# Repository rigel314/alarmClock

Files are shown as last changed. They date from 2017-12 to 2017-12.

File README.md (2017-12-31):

alarmClock
========
# About
My fiancé wanted an alarm clock that simulated a sunrise before ringing.  Since all the ones you can buy are expensive, dumb, or both, I decided to make one.

# Dependencies
 * [My fork of firelizzard's Nokia LCD library](https://github.com/rigel314/Arduino-LCD-Screen), which is a submodule
  * This should be installed as a normal Arduino library. For me, this was:
    * `git submodule update --init`
    * `cp -a Arduino-LCD-Screen ../../libraries/`
 * [TimerOne](https://github.com/PaulStoffregen/TimerOne) as installed by the teensy installer
 * [TimeLib](https://github.com/PaulStoffregen/Time) as installed by the teensy installer
 * [DS1307RTC](https://github.com/PaulStoffregen/DS1307RTC) as installed through the Arduino IDE "Manage Libraries" interface

# Hardware
 * 3-color LED strip
 * Resistors and transistors
 * DS1307 Real Time Clock
 * MCP4725 I2C DAC for audio
 * Speaker
 * Nokia 5110 84x48 pixel LCD screen
 * Arduino Duemilanove/Uno with atmega328P
 * 12V power supply

See the [/eagle](https://github.com/rigel314/alarmClock/tree/master/eagle) folder in this repo for the board layout.
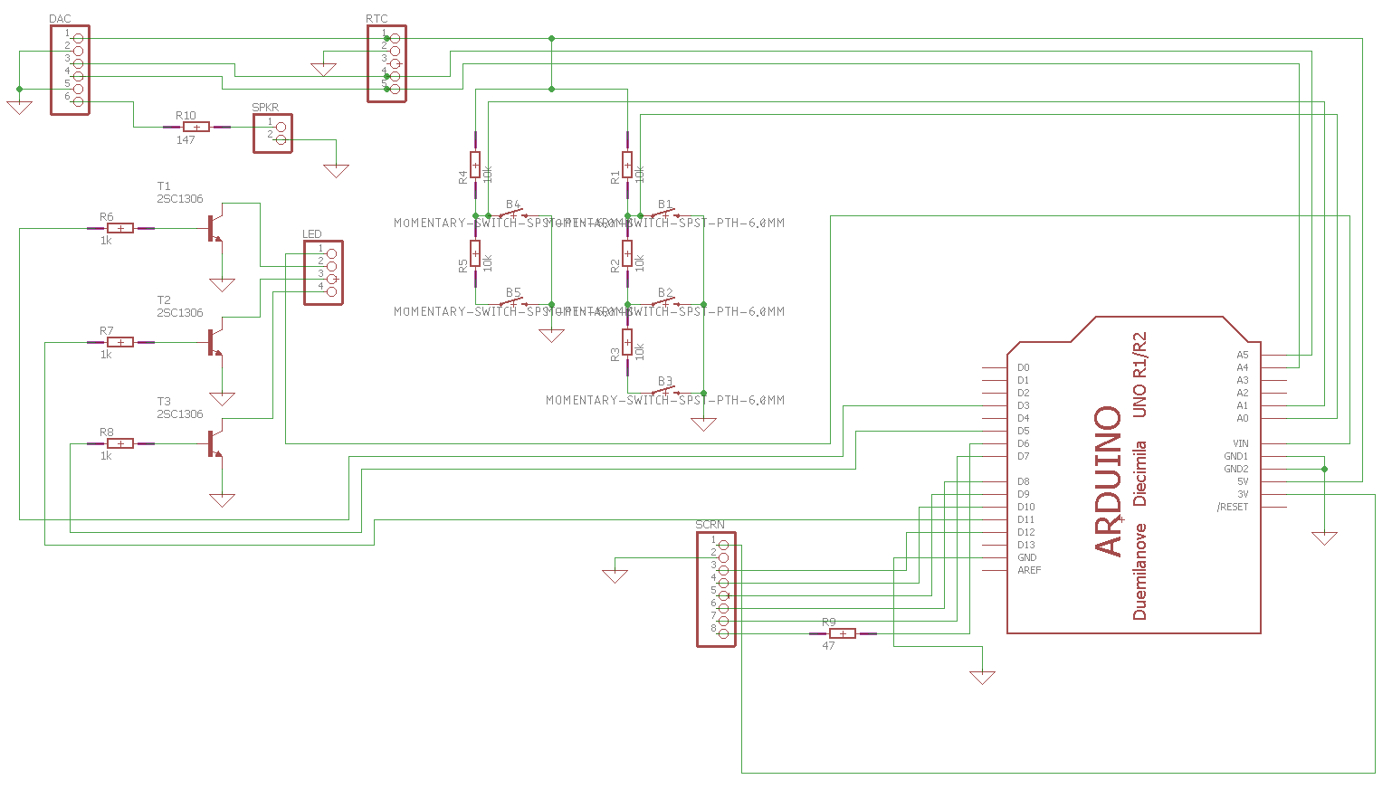
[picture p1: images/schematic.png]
Schematic


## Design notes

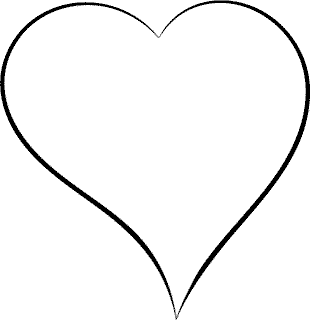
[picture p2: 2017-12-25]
images/heart-320.bmp

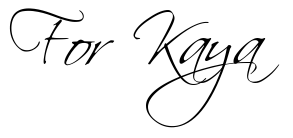
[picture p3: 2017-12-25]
images/forkaya.PNG

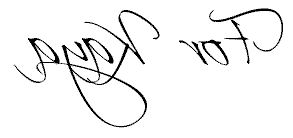
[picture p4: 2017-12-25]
images/forkaya.bmp

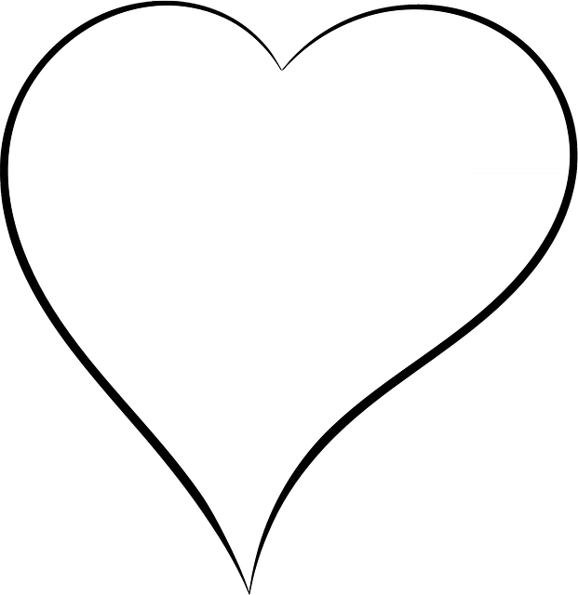
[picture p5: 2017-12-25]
images/heart-264496_640.png

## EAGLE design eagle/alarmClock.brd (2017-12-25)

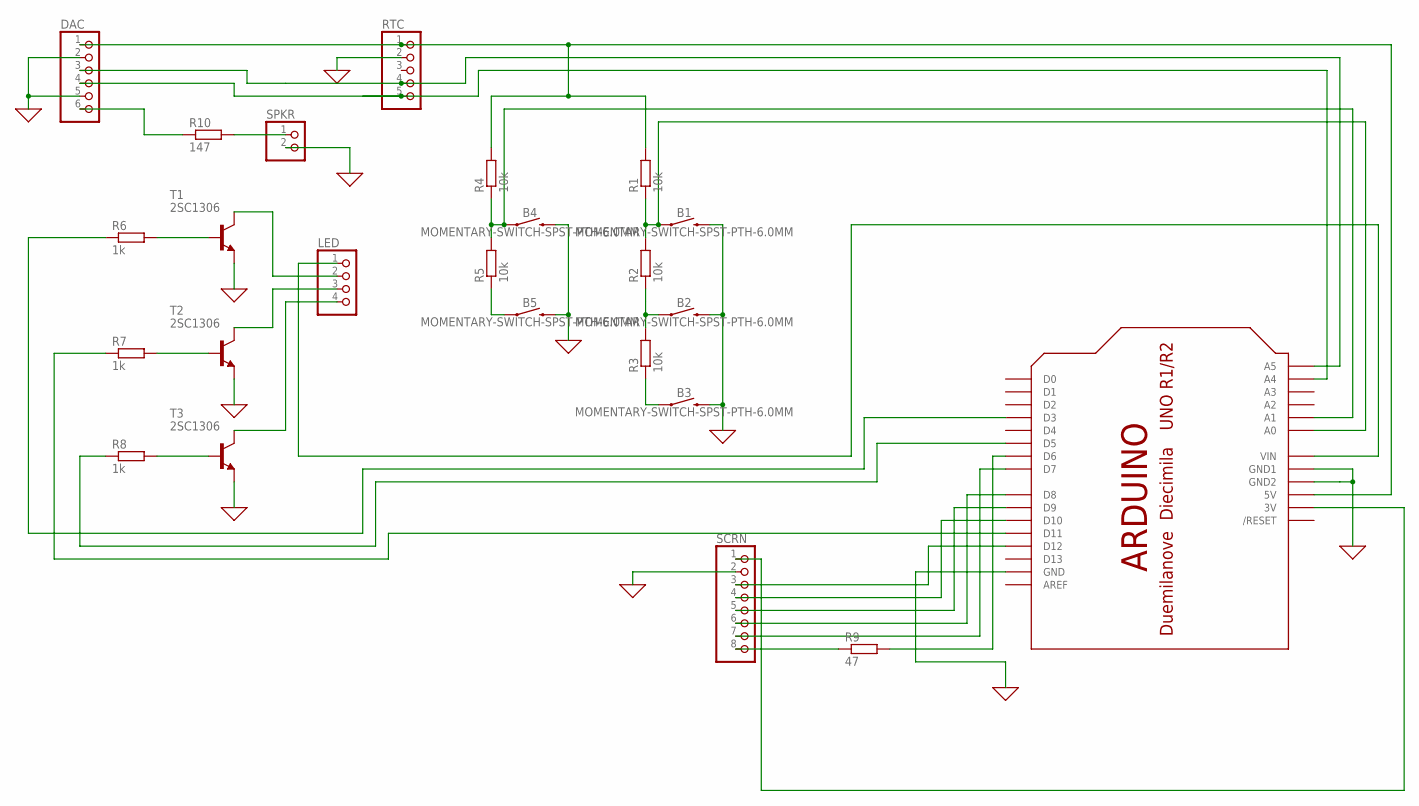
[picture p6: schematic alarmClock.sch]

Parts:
B1, B2, B3, B4, B5: MOMENTARY-SWITCH-SPST-PTH-6.0MM; TACTILE_SWITCH_PTH_6.0MM
DAC: PINHD-1X6; 1X06
LED: PINHD-1X4; 1X04
R1, R2, R3, R4, R5: 10k; 0204/7
R6, R7, R8: 1k; 0204/7
R9: 47; 0204/7
R10: 147; 0204/7
RTC: PINHD-1X5; 1X05
SCRN: PINHD-1X8; 1X08
SPKR: PINHD-1X2; 1X02
T1, T2, T3: 2SC1306; TO220BV
U$1: ARDUINOUNO; ARDUINO

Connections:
0: B1.3 (2), B2.3 (2), B3.3 (2), B4.3 (2), B5.3 (2), DAC.2, DAC.5, RTC.2, SCRN.2, SPKR.2, T1.3 (E), T2.3 (E), T3.3 (E), U$1.GND, U$1.GND1, U$1.GND2
unnamed: B1.1, R1.1, R2.2, U$1.A0
unnamed: B3.1, R3.1
unnamed: B2.1, R2.1, R3.2
unnamed: B5.1, R5.1
unnamed: B4.1, R4.1, R5.2, U$1.A1
unnamed: R6.2, T1.1 (B)
unnamed: R8.2, T3.1 (B)
unnamed: R7.2, T2.1 (B)
unnamed: DAC.4, RTC.5, U$1.A4
unnamed: DAC.3, RTC.4, U$1.A5
unnamed: DAC.1, R1.2, R4.2, RTC.1, U$1.5V
unnamed: DAC.6, R10.1
unnamed: LED.1, U$1.VIN
unnamed: LED.2, T1.2 (C)
unnamed: LED.4, T3.2 (C)
unnamed: LED.3, T2.2 (C)
unnamed: R6.1, U$1.D3
unnamed: R8.1, U$1.D5
unnamed: SCRN.7, U$1.D7
unnamed: R9.2, U$1.D6
unnamed: SCRN.6, U$1.D8
unnamed: R7.1, U$1.D11
unnamed: SCRN.5, U$1.D9
unnamed: SCRN.4, U$1.D10
unnamed: SCRN.3, U$1.D12
unnamed: SCRN.1, U$1.3V
unnamed: R9.1, SCRN.8
unnamed: R10.2, SPKR.1

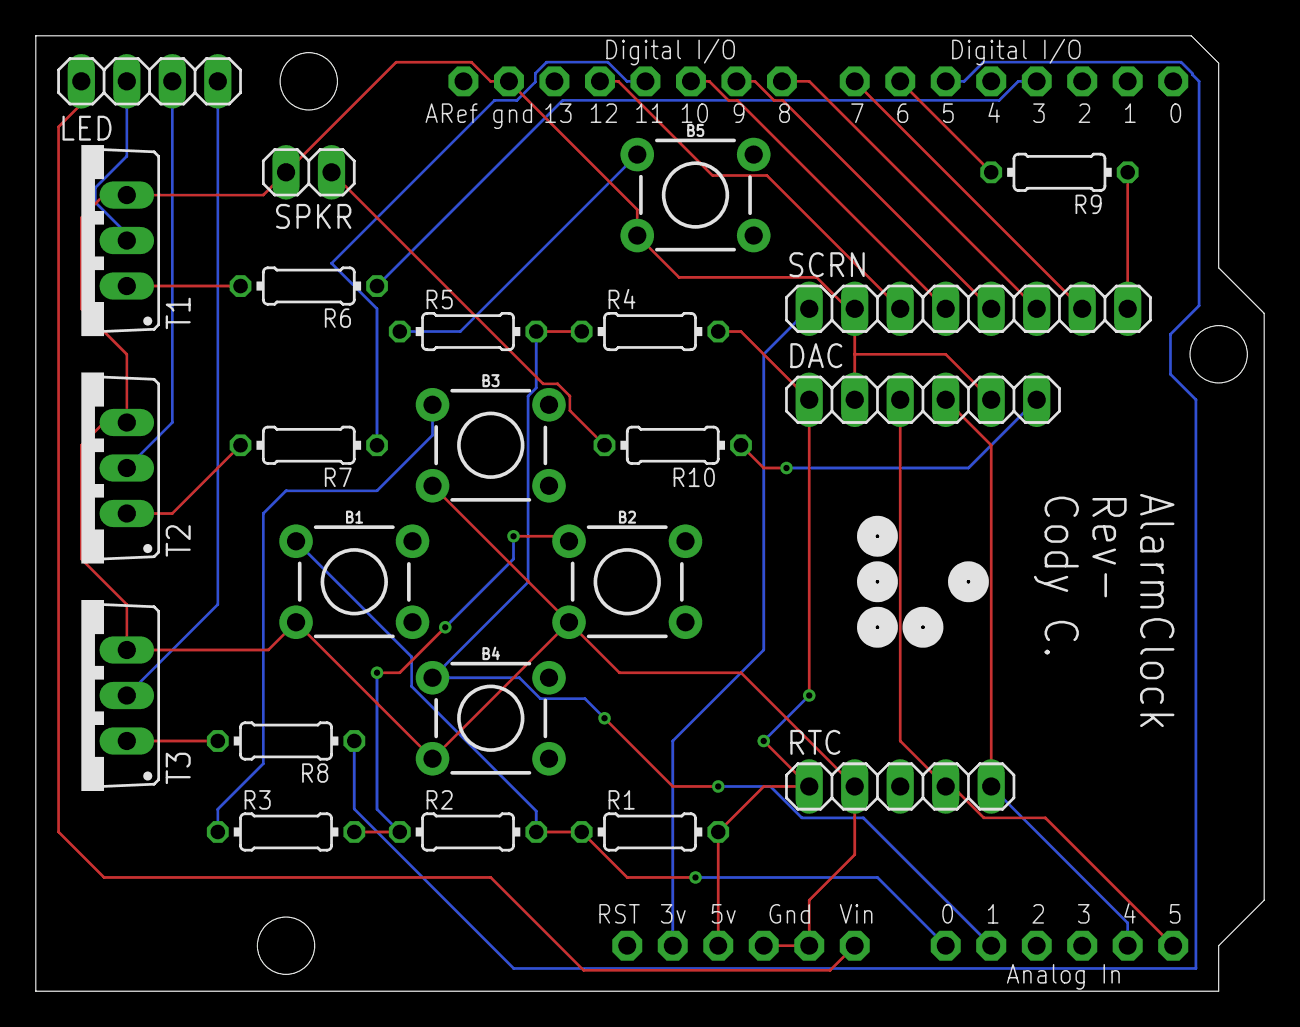
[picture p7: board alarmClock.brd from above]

Board: 2 copper layers, 68.6 x 53.3 mm, 24 parts (0 on the bottom side), 29 nets.

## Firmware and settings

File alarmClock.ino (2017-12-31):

// TODO: add function that prints a help icon on the screen that takes an array of enums, which are indexes into a string table.
// TODO: add 2min timeout for modes that goes back to normal mode, so the alarm still goes off.
// TODO: reverify 8kHz sound, since I removed a mask

#include <TimerOne.h>
#include <TimeLib.h>
#include <DS1307RTC.h>
#include <Wire.h>
#include <avr/pgmspace.h>
// #include <EEPROM.h>

#include "common.h"
#include "modes.h"

volatile unsigned char gotTimer1 = 0;

LCD lcd(SCRN_SCLK_PIN, SCRN_MOSI_PIN, SCRN_DC_PIN, SCRN_RST_PIN, SCRN_SCE_PIN);

const char sound[] PROGMEM =
#include "bird.h" // This has the data and a semicolon

const char lookup[] = "0123456789ABCDEF";
const char* emptyLine = "              ";

struct alarm alarms[nALARMS] = {{0,0,0}};

// Called via timer interrupt
void timer1inter()
{
	gotTimer1 = 1;
	// logobj("inter");
}

void setup()
{
	Serial.begin(115200); // For debug (owns pins 0 and 1)
	
	// TWBR = ((F_CPU / 400000L) - 16) / 2; // Set I2C frequency to 400kHz
	Wire.setClock(400000L);
	
	Timer1.initialize(1000000);
	Timer1.attachInterrupt(timer1inter);
	
	lcd.initialize();
	lcd.sendCommands("\x21\xAC\x20");
	
	// set time sync to read from the RTC every 5min. (which is actually sync()'d in now() if it detects elapsed time >= 300s)
	setSyncProvider(RTC.get);
	// setSyncInterval(10);
	
	// Initial screen
	tmElements_t tm;
	breakTime(now(), tm);
	char timestr[] = "now - 15:37   ";
	timestr[6] = lookup[tm.Hour/10];
	timestr[7] = lookup[tm.Hour%10];
	timestr[9] = lookup[tm.Minute/10];
	timestr[10] = lookup[tm.Minute%10];
	lcd.sendString(0, 0, timestr);
	lcd.sendString(5, 0, "mode: NORMAL");
	
	// Set pin directions
	pinMode(BUT_PIN1, INPUT);
	pinMode(BUT_PIN2, INPUT);
	
	pinMode(RED_PIN, OUTPUT);
	pinMode(GRN_PIN, OUTPUT);
	pinMode(BLU_PIN, OUTPUT);
	
	// get saved settings
	// TODO: read alarm time and other settings(backlight intensity?) from EEPROM/RTCram
}

void loop()
{
	static enum but prevBut = but_NONE;
	static int prev1Val = 0;
	static int prev2Val = 0;
	static char backlight = 0;
	static enum mode mode = mode_NORMAL;
	static char longPress = 0;
	static int longCount = 0;
	
	enum but but, realbut;
	
	// Handle interrupt
	if(gotTimer1)
	{
		gotTimer1 = 0;
		tmElements_t tm;
		
		breakTime(now(), tm);
		
		char timestr[] = "now - 15:37   ";
		
		timestr[6] = lookup[tm.Hour/10];
		timestr[7] = lookup[tm.Hour%10];
		timestr[9] = lookup[tm.Minute/10];
		timestr[10] = lookup[tm.Minute%10];
		
		lcd.sendString(0, 0, timestr);
	}
	
	// Figure out which button is pressed
	int but1Val = analogRead(BUT_PIN1);
	int but2Val = analogRead(BUT_PIN2);
	
	if(histequal(but1Val, prev1Val, 10) && histequal(but2Val, prev2Val, 10))
	{
		if(histequal(but1Val, 1024, 20) && histequal(but2Val, 1024, 20))
			but = but_NONE;
		else if(histequal(but1Val, 0, 70))
			but = but_LEFT;
		else if(histequal(but1Val, 512, 70))
			but = but_RIGHT;
		else if(histequal(but1Val, 682, 70))
			but = but_UP;
		else if(histequal(but2Val, 0, 70))
			but = but_DOWN;
		else if(histequal(but2Val, 512, 70))
			but = but_SELECT;
		else
			but = prevBut;
	}
	else
	{
		but = prevBut;
	}
	
	// Don't send a button event unless a button has been released
	realbut = but_NONE;
	if(but == but_NONE && prevBut != but_NONE) // button released
	{
		if(longPress) // Also don't send one if longpress was sent
			longPress = 0;
		else
			realbut = prevBut;
		longCount = 0;
	}
	
	if(longCount == 5000 && !longPress)
	{
		longPress = 1;
		realbut = (enum but)(but + 5);
	}
	if(but != but_NONE)
	{
		if(longPress && longCount % 200 == 1)
		{
			realbut = (enum but)(but + 10); // Unless a repeat should be sent
		}
		longCount++;
	}
	
	// handle buttons globally
	if(realbut == but_SELECT_LONG)
	{
		// logwobj("B5", but2Val);
		realbut = but_NONE;
		backlight = !backlight;
		analogWrite(SCRN_LED_PIN, (backlight) ? 10 : 0);
	}
	
	enum mode modebak = mode;
	
	mode = modeMux(mode, &realbut);
	
	// default actions for buttons
	if(realbut == but_LEFT)
		mode = (enum mode)(mode - 1);
	if(realbut == but_RIGHT)
	{
		mode = (enum mode)(mode + 1);
		// logwobj("default mode++ handler", modebak);
	}
	
	if(mode == mode_NMODES)
	{
		mode = mode_NORMAL;
	}
	if(mode == mode_INVALID)
	{
		// logwobj("default invalid mode handler", modebak);
		mode = mode_DEMO;
	}
	
	if(mode != modebak)
	{
		switch(mode)
		{
			default:
				logwobj("weird mode", mode);
				mode = mode_NORMAL;
				// intentional fallthrough
			case mode_NORMAL:
				lcd.sendString(5, 0, "mode: NORMAL  ");
				break;
			case mode_SETTIME:
				lcd.sendString(5, 0, "mode: SETTIME ");
				break;
			case mode_SETALARM:
				lcd.sendString(5, 0, "mode: SETALARM");
				break;
			case mode_DEMO:
				lcd.sendString(5, 0, "mode: DEMO    ");
				break;
		}
	}
	
	prevBut = but;
	prev1Val = but1Val;
	prev2Val = but2Val;
}

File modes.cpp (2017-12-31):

#include <Arduino.h>
#include <Wire.h>
#include <TimeLib.h>
#include <DS1307RTC.h>

#include "modes.h"

static const char* fields[] = {"year", "month", "day", "hour", "minute", "second"};
static const uint8_t min[] = {0, 1, 1, 0, 0, 0};
static uint8_t max[] = {255, 12, 31, 23, 59, 59};
const char* days = "SMTWHFS";

#define LEAP_YEAR(Y) ( ((1970+Y)>0) && !((1970+Y)%4) && ( ((1970+Y)%100) || !((1970+Y)%400) ) )

static const uint8_t monthDays[]={31,28,31,30,31,30,31,31,30,31,30,31}; // API starts months from 1, this array starts from 0

enum mode normmode(enum mode mode, enum but* butp)
{
	enum but but = *butp;
	(void) but;
	return mode;
}

enum mode stimemode(enum mode mode, enum but* butp)
{
	static char entry = 0;
	static tmElements_t tm;
	char len;
	
	enum but but = *butp;
	
	if(!entry && but == but_SELECT)
	{
		*butp = but_NONE;
		entry = 1;
		breakTime(now(), tm);
		char str[15];
		len = snprintf(str, 15, "%s: %04d", fields[0], (int)tm.Year + 1970);
		for(int i = len; i < 14; i++)
			str[i] = ' ';
		str[14] = '\0';
		lcd.sendString(4, 0, str);
		
		return mode;
	}
	
	if(entry)
	{
		char str[15];
		
		uint8_t* fld = &((uint8_t*)&tm)[7-entry-(entry > 3)]; // index into the correct field in the tmElements_t struct
		// if(but != but_NONE)
		// 	logwobj("offset", (int)(fld - (uint8_t*)&tm));
		int val = (int)*fld;
		int off = 0;
		const char* fmt = "%s: %02d";
		if(entry == 1)
		{
			off = 1970; // Adjust year
			fmt = "%s: %04d";
		}
		
		max[2] = monthDays[tm.Month - 1];
		if(tm.Month == 2 && LEAP_YEAR(tm.Year))
		{
			max[2] = 29;
		}
		if(tm.Day > max[2])
		{
			tm.Day = max[2];
		}
		
		switch(but)
		{
			case but_LEFT:
				entry--;
				break;
				
			case but_SELECT:
				entry = 6;
				// Intentional fallthrough
			case but_RIGHT:
				entry++;
				if(entry == 7)
				{
					time_t tme = makeTime(tm);
					RTC.set(tme);
					setTime(tme);
					entry = 0;
				}
				break;
			
			case but_UP:
			case but_UP_RPT:
				if(val < max[entry - 1])
					(*fld)++;
				val = *fld;
				val += off; // Adjust year
				len = snprintf(str, 15, fmt, fields[entry - 1], val);
				for(int i = len; i < 14; i++)
					str[i] = ' ';
				str[14] = '\0';
				lcd.sendString(4, 0, str);
				break;
			
			case but_DOWN:
			case but_DOWN_RPT:
				if(val > min[entry - 1])
					(*fld)--;
				val = *fld;
				val += off; // Adjust year
				len = snprintf(str, 15, fmt, fields[entry - 1], val);
				for(int i = len; i < 14; i++)
					str[i] = ' ';
				str[14] = '\0';
				lcd.sendString(4, 0, str);
				break;
				
			default:
				break;
		}
		if((but == but_LEFT || but == but_RIGHT) && entry)
		{
			off = 0;
			fmt = "%s: %02d";
			if(entry == 1)
			{
				off = 1970; // Adjust year
				fmt = "%s: %04d";
			}
			
			fld = &((uint8_t*)&tm)[7-entry-(entry > 3)];
			val = *fld;
			val += off;
			len = snprintf(str, 15, fmt, fields[entry - 1], val);
			for(int i = len; i < 14; i++)
				str[i] = ' ';
			str[14] = '\0';
			lcd.sendString(4, 0, str);
		}
		if(entry == 0)
		{
			lcd.sendString(4, 0, (char*)emptyLine);
		}
		
		*butp = but_NONE;
	}
	
	return mode;
}

enum mode salrmmode(enum mode mode, enum but* butp)
{
	static char entry = 0;
	static char newentry = 0;
	static int alarmChoice;
	static char val = 0;
	// static char newval = 0;
	static struct alarm alrm = {0,0,0};
	
	char len;
	enum but but = *butp;
	
	// begin entry
	if(!entry && but == but_SELECT)
	{
		char str[19];
		*butp = but_NONE;
		entry = 1;
		alarmChoice = 0;
		alrm = alarms[alarmChoice];
		if(nALARMS == 1) // Maybe make this an #if
		{
			entry++;
			val = alrm.hour;
			len = snprintf(str, 19, "set: %s%02d%s:%02d", LCD::reverseVideoOn, (int)alrm.hour, LCD::reverseVideoOff, (int)alrm.min);
		}
		else
		{
			val = alarmChoice;
			len = snprintf(str, 19, "alarm: %d", (int)alarmChoice+1);
		}
		for(int i = len; i < 18; i++)
			str[i] = ' ';
		str[18] = '\0';
		lcd.sendString(4, 0, str);
		
		return mode;
	}
	
	// actually do entry
	if(entry)
	{
		// logwobj("but IN:", *butp);
		char str[19];
		char str3[15];
		newentry = entry;
		// newval = val;
		
		// handle buttons
		switch(but)
		{
			case but_LEFT:
				newentry--;
				if(nALARMS == 1 && newentry == 1)
					newentry--;
				break;
				
			case but_SELECT:
				newentry = 11;
				// Intentional fallthrough
			case but_RIGHT:
				newentry++;
				if(newentry == 12)
				{
					newentry = 0;
				}
				break;
			
			case but_UP:
			case but_UP_RPT:
				val++;
				break;
			
			case but_DOWN:
			case but_DOWN_RPT:
				val--;
				break;
				
			default:
				break;
		}
		
		char entrychanged = (entry != newentry);
		char shft = (6-(entry-5)); // bit shift for weekday selection
		
		// update storage variable on entry change for the entry you just left
		if(entrychanged)
		{
			switch(entry)
			{
				case 1:
					alarmChoice = val;
					break;
				case 2:
					alrm.hour = val;
					break;
				case 3:
					alrm.min = val;
					break;
				case 4:
					alrm.enDayEn = (alrm.enDayEn & 0x7F) | val<<7;
					break;
				case 5:
				case 6:
				case 7:
				case 8:
				case 9:
				case 10:
				case 11:
					alrm.enDayEn = (alrm.enDayEn & ~(1 << shft)) | (val << shft);
					// logwobj("enDayEn", (int)alrm.enDayEn, HEX);
					break;
				default:
					break;
			}
		}
		
		entry = newentry;
		// val = newval;
		
		strcpy(str3, emptyLine);
		
		char len;
		shft = (6-(entry-5)); // calculate this again on the new entry
		
		// create correct line 4 for newentry and newval
		// update temp var from storage var on entry change for the entry you just changed to
		switch(entry)
		{
			case 1:
				if(entrychanged)
					val = alarmChoice;
				if(val < 1)
					val = nALARMS;
				if(val > nALARMS)
					val = 1;
				len = snprintf(str, 19, "alarm: %s%d%s", LCD::reverseVideoOn, val, LCD::reverseVideoOff);
				break;
			case 2:
				if(entrychanged)
					val = alrm.hour;
				if(val < 0)
					val = 23;
				if(val > 23)
					val = 0;
				len = snprintf(str, 19, "set: %s%02d%s:%02d", LCD::reverseVideoOn, (int)val, LCD::reverseVideoOff, (int)alrm.min);
				break;
			case 3:
				if(entrychanged)
					val = alrm.min;
				if(val < 0)
					val = 59;
				if(val > 59)
					val = 0;
				len = snprintf(str, 19, "set: %02d:%s%02d%s", (int)alrm.hour, LCD::reverseVideoOn, (int)val, LCD::reverseVideoOff);
				break;
			case 4:
				if(entrychanged)
					val = !!(alrm.enDayEn & 0x80);
				if(val < 0)
					val = 1;
				if(val > 1)
					val = 0;
				len = snprintf(str, 19, "enable: %s%s%s", LCD::reverseVideoOn, (val) ? "yes" : "no", LCD::reverseVideoOff);
				break;
			case 5:
			case 6:
			case 7:
			case 8:
			case 9:
			case 10:
			case 11:
				if(entrychanged)
					val = !!(alrm.enDayEn & (1 << shft));
				if(val < 0)
					val = 1;
				if(val > 1)
					val = 0;
				len = 16;
				strcpy(str, "on: ");
				strcpy(str3, "off:");
				for(int i = 0; i < 7; i++)
				{
					uint8_t curval = (alrm.enDayEn & ~(1 << shft)) | (val << shft);
					if(i == entry-5)
						memcpy(&str[4+i], LCD::reverseVideoOn, 2);
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

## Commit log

2017-12-23 Add LED strip and Screen commanding
2017-12-23 sane buttons
2017-12-24 Add Eagle project
    [alarmClock.brd, alarmClock.sch]
2017-12-25 Add bird noise PoC
    [alarmClock.ino]
2017-12-25 Update Rev- for sending to fab
    [alarmClock.brd, alarmClock.sch]
2017-12-26 Add concept of unhandled buttons and default actions.
2017-12-26 Fix needing to mask off high bits during audio play by casting pgm_read_byte to signed int8.
    [modes.cpp]
2017-12-26 Add button repeat.
2017-12-31 Add schematic
2017-12-31 Pass varargs to serial.println

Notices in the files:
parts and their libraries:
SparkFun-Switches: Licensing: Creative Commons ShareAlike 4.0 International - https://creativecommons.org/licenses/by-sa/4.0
